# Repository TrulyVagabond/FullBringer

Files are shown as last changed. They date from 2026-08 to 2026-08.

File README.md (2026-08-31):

[][contributors-url]
[][forks-url]
[][stars-url]
[][issues-url]
[][license-url]

<br />
<div align="center">
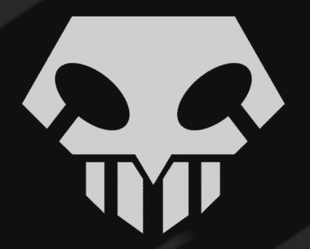
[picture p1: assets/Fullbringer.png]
  
  <h3 align="center">FullBringer</h3>

  <p align="center">
    A Cooler PCB Card
    <br />
    <br />
    <a href="https://github.com/TrulyVagabond/FullBringer/blob/main/JOURNAL.md">Journal</a>
    &middot;
    <a href="https://github.com/TrulyVagabond/FullBringer/issues">Report Bug</a>
    &middot;
    <a href="https://github.com/TrulyVagabond/FullBringer/issues">Request Feature</a>
  </p>
</div>

## What is FullBringer?

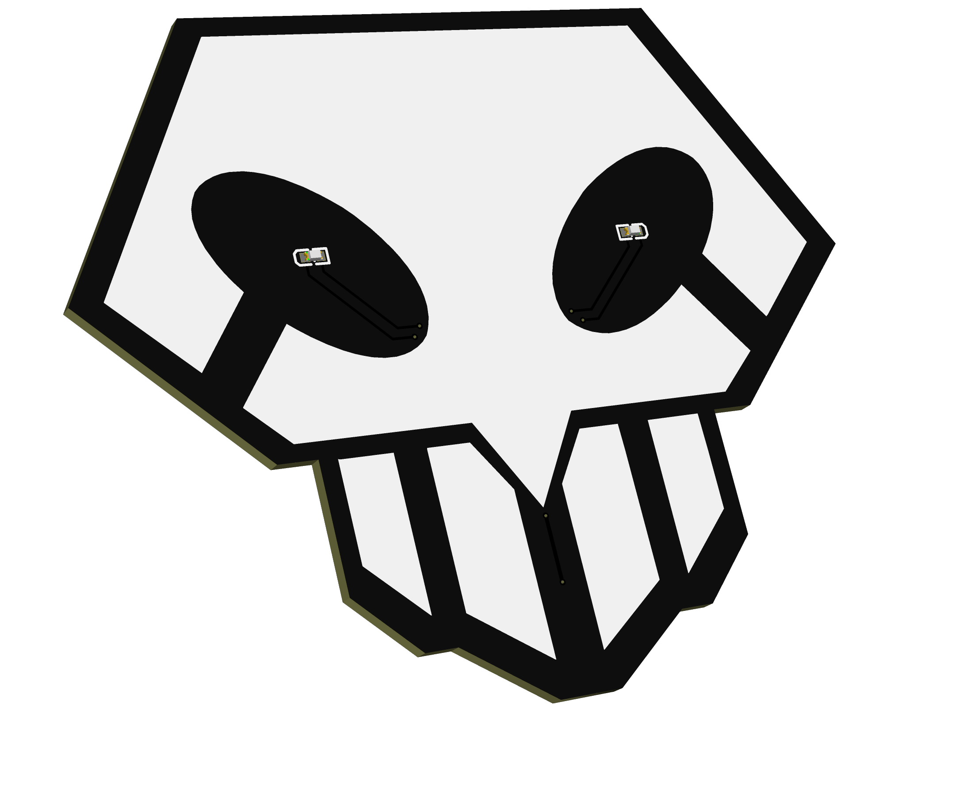
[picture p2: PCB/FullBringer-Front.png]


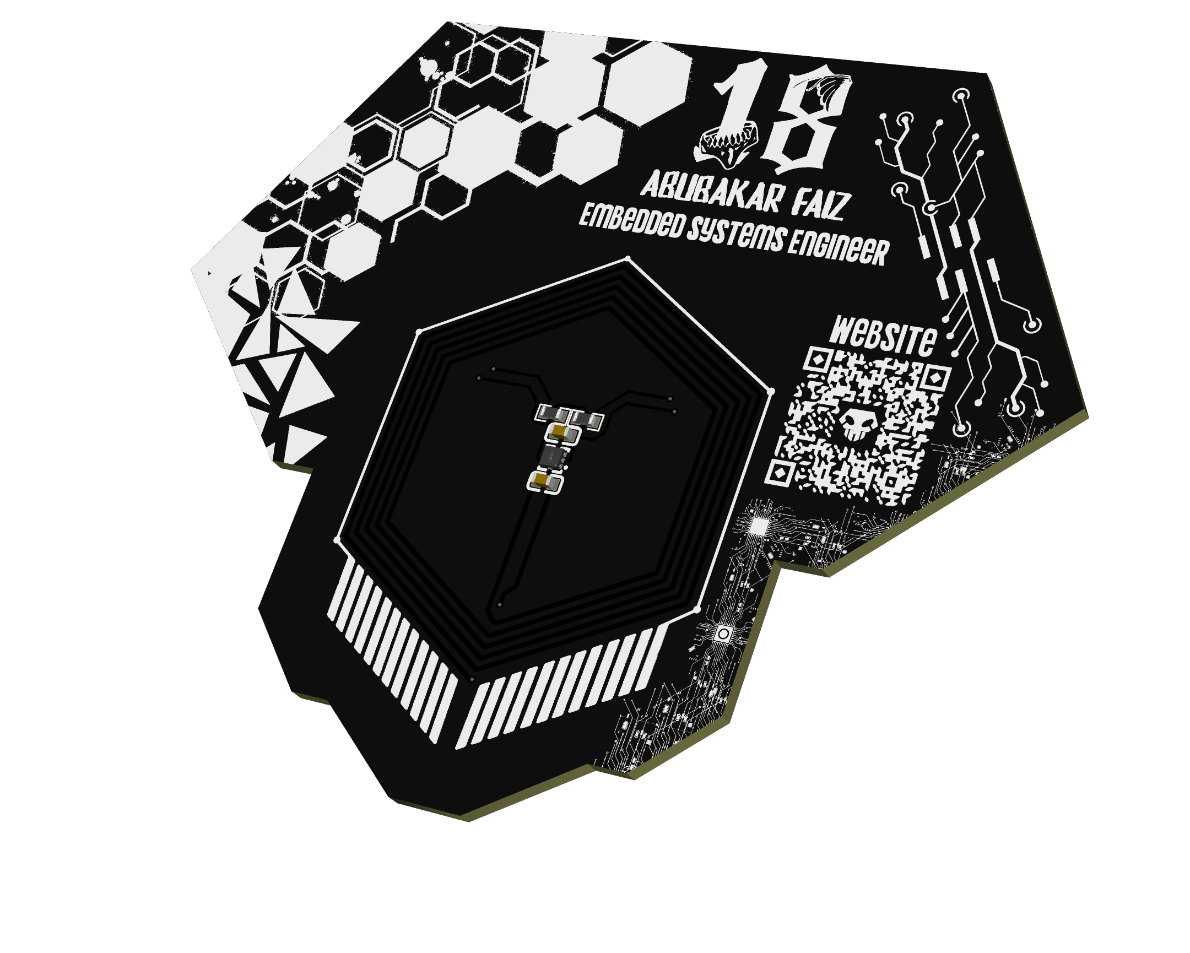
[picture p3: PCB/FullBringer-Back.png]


FullBringer is A PCB Business/Portfolio/ID Card with NFC and Design Inspired by Bleach. There are 2 LED's on the Front and the Entire Circuit on the Bottom Layer. This is Purely Designed to Look Cooler and Impress Recruiters or Friends. The integrated planar antenna harvests power from the phone's magnetic field to illuminate two red LEDs embedded in the skull's eye sockets, while simultaneously broadcasting an NDEF payload (custom URL, or GitHub portfolio) directly to the device.

### Built With

* [][EasyEDA-url]
* [][Inkscape-url]

## Getting Started

To get Your own FullBringer, you need two things.

- PCB
- Money

### Ordering the PCB

1. Navigate to the Gerber Files in the **"Gerber"** Folder. 

2. Download the ".zip" File

3. Upload this '.zip' file to a custom PCB manufacturer (Like PCBWay, OSH Park or JLCPCB)

4. Standard Manufacturing Settings (1.6mm thickness, HASL finish) work Perfectly for this Board.

## Bills Of Materials (BOM)

| Item | Designator | Qty | Value / Param | Package | Description | Manufacturer | MPN | JLCPCB / LCSC Part # |
| :---: | :--- | :---: | :--- | :--- | :--- | :--- | :--- | :---: |
| 1 | **U1** | 1 | 13.56 MHz | XQFN-8 (1.6×1.6mm) | NTAG I²C Plus NFC Transponder IC with Energy Harvesting Rail (`VOUT`) | NXP Semiconductors | `NT3H1101W0FHKH` | [C73156](https://www.lcsc.com/product-detail/C73156.html) |
| 2 | **C1** | 1 | 1 µF, 50V, X5R | 0603 | Energy Harvesting Buffer & Decoupling Capacitor (VOUT to GND) | Samsung Electro-Mechanics | `CL10A105KB8NNNC` | [C15849](https://www.lcsc.com/product-detail/C15849.html) |
| 3 | **C2** | 1 | 33 pF, 50V, C0G/NP0 | 0603 | RF Tank Tuning Capacitor (Parallel across LA/LB terminals) | Samsung Electro-Mechanics | `CL10C330JB8NNNC` | [C1663](https://www.lcsc.com/product-detail/C1663.html) |
| 4 | **R1, R2** | 2 | 470 Ω, 1% | 0603 | Current-Limiting Resistors for Eye LEDs (~1.2 mA per branch) | UNI-ROYAL (厚声) | `0603WAF4700T5E` | [C23179](https://www.lcsc.com/product-detail/C23179.html) |
| 5 | **LED1, LED2** | 2 | 620–625 nm (Red) | 0603 (1608 Metric) | High-Efficiency Red SMD Diffused LEDs (Skull Eye Sockets) | KENTO (广东风华) | `KT-0603R` | [C2286](https://www.lcsc.com/product-detail/C2286.html) |
| 6 | **ANT** | 1 | ~1.65 µH | PCB Trace | 5-Turn Hexagonal Planar Spiral Inductor (0.4 mm width / 0.4 mm spacing) | Custom Embedded | Embedded Copper | *Integrated* | 

### **Total: $6-7** (DON'T SAY IT)

## Using FullBringer

You Just need to Solder the Chip/Capacitors etc (unless you bought from PCBWay). Then Just use the Free NFC tools App for Android/IOS to Setup the NFC. Thats it, your Fullbringer is Ready!

## Special Thanks:

- **EasyEDA** for the Amazing PCB Designing Free Software.

- **Hack Club** for making me Motivated enough to make this.

## License

This Project is Distributed Under MIT License. Check License.txt for More Information.

<!-- MARKDOWN LINKS & IMAGES -->
[contributors-shield]: https://img.shields.io/github/contributors/TrulyVagabond/FullBringer.svg?style=for-the-badge
[contributors-url]: https://github.com/TrulyVagabond/FullBringer/graphs/contributors

[forks-shield]: https://img.shields.io/github/forks/TrulyVagabond/FullBringer.svg?style=for-the-badge
[forks-url]: https://github.com/TrulyVagabond/FullBringer/network/members

[stars-shield]: https://img.shields.io/github/stars/TrulyVagabond/FullBringer.svg?style=for-the-badge
[stars-url]: https://github.com/TrulyVagabond/FullBringer/stargazers

[issues-shield]: https://img.shields.io/github/issues/TrulyVagabond/FullBringer.svg?style=for-the-badge
[issues-url]: https://github.com/TrulyVagabond/FullBringer/issues

[license-shield]: https://img.shields.io/github/license/TrulyVagabond/FullBringer.svg?style=for-the-badge
[license-url]: https://github.com/TrulyVagabond/FullBringer/blob/main/LICENSE

[EasyEDA]: https://img.shields.io/badge/EasyEDA-0177D7?style=for-the-badge
[EasyEDA-url]: https://easyeda.com/

[FreeCAD]: https://img.shields.io/badge/FreeCAD-2D9CDB?style=for-the-badge&logo=freecad&logoColor=white
[FreeCAD-url]: https://www.freecad.org/

[Inkscape]: https://img.shields.io/badge/Inkscape-000000?style=for-the-badge&logo=inkscape&logoColor=white
[Inkscape-url]: https://inkscape.org/

<br>

###### Note: A.I was only used for Research Purposes.

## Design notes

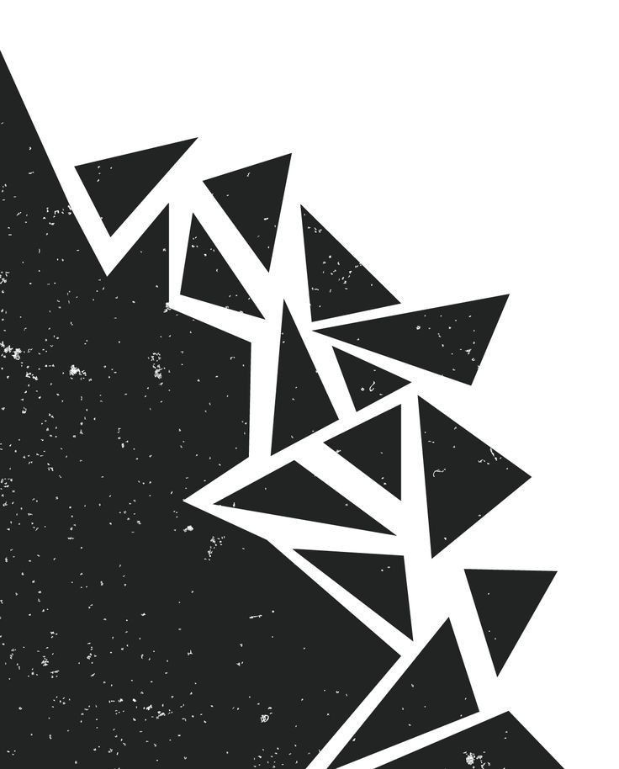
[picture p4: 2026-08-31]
assets/art3.jpg

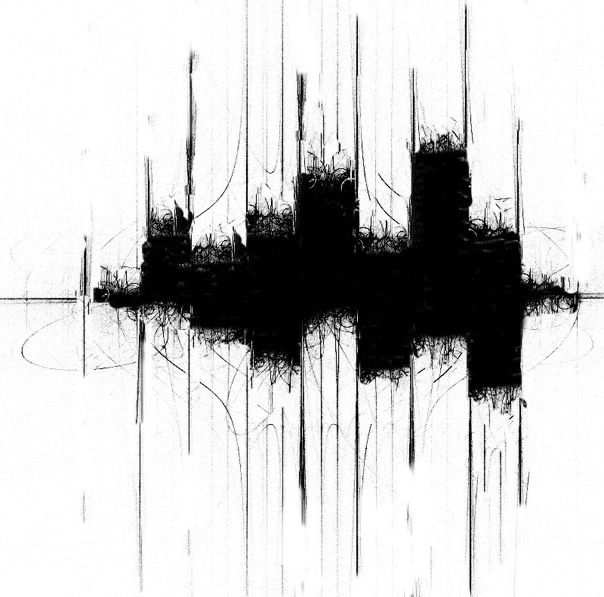
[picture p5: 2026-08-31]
assets/art2.jpg

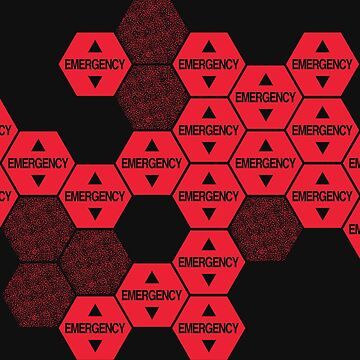
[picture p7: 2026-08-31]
assets/art7.jpg

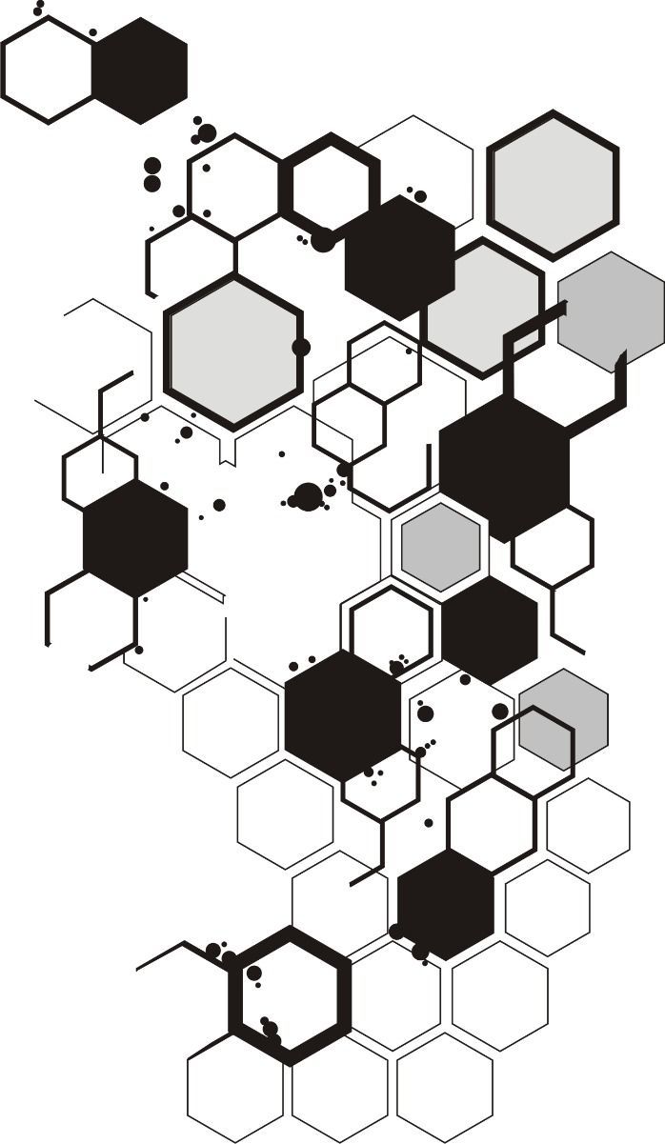
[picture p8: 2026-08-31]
assets/art1.jpg

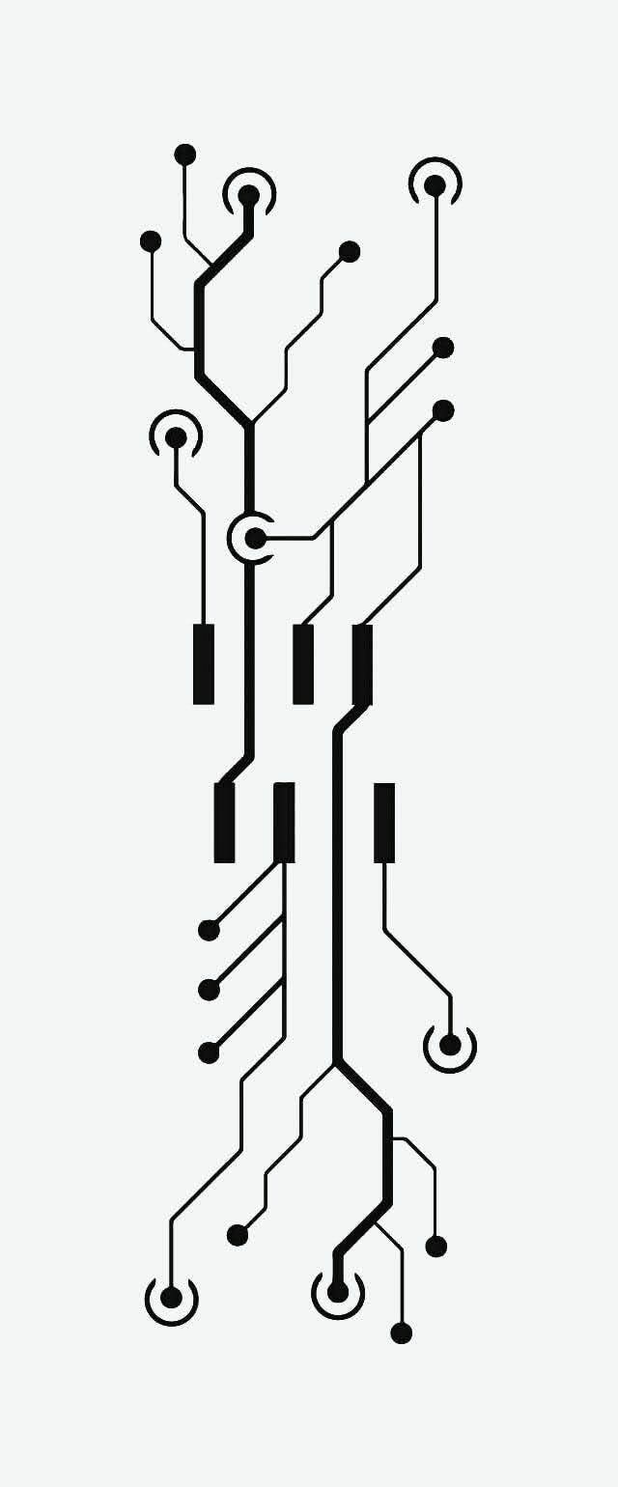
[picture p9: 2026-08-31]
assets/art.jpg

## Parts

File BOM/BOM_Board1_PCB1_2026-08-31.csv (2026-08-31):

No. | Quantity | Comment | Designator | Footprint | Value | Manufacturer Part | Manufacturer | Supplier Part | Supplier | Name | LCSC Stock | LCSC Price
1 | 1 | 1uF | C1 | C0603 | 1uF | CL10A105KB8NNNC | SAMSUNG(三星) | C15849 | LCSC | 1uF
2 | 1 | 33pF | C2 | C0603 | 33pF | CL10B104KA8NNNC | SAMSUNG(三星) |  | LCSC | 33pF
3 | 2 | KT-0603R | LED1,LED2 | LED-SMD_L1.6-W0.8-R-RD |  | KT-0603R | KENTO | C2286 | LCSC | KT-0603R
4 | 2 | 470Ω | R1,R2 | R0603 | 470Ω | 0603WAF4700T5E | UNI-ROYAL(厚声) | C23179 | LCSC | 470Ω
5 | 1 | 13.56MHz | U1 | XQFN-8_L1.6-W1.6-P0.50-BR | 13.56MHz | NT3H1101W0FHKH | NXP(恩智浦) | C73156 | LCSC | 13.56MHz

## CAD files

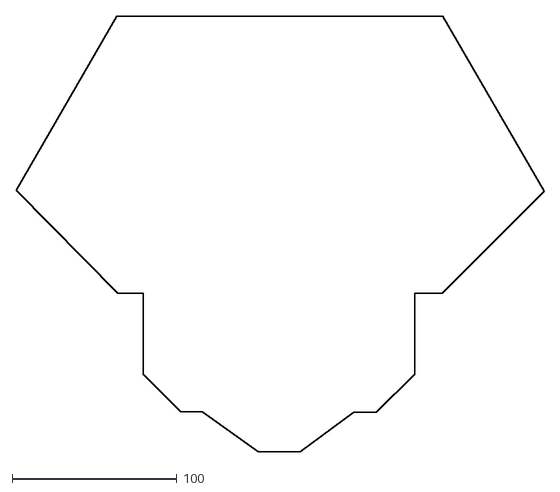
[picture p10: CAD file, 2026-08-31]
assets/Fullllbringer.dxf
320.6 x 264.6

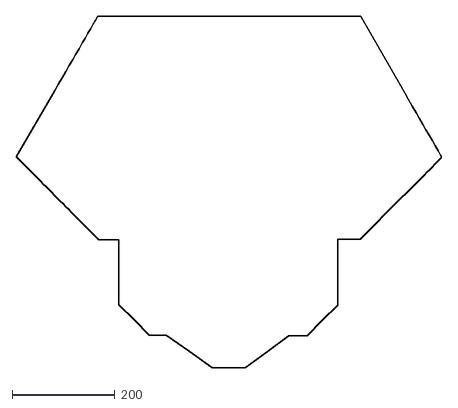
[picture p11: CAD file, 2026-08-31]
assets/Fullbringer.dxf
825.5 x 682.0

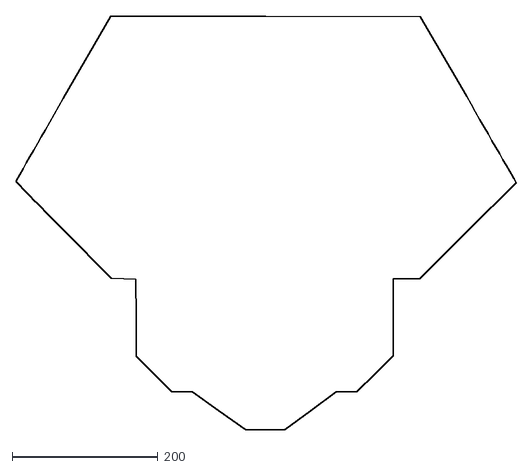
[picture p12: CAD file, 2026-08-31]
assets/Fulllbringer.dxf
685.4 x 567.0

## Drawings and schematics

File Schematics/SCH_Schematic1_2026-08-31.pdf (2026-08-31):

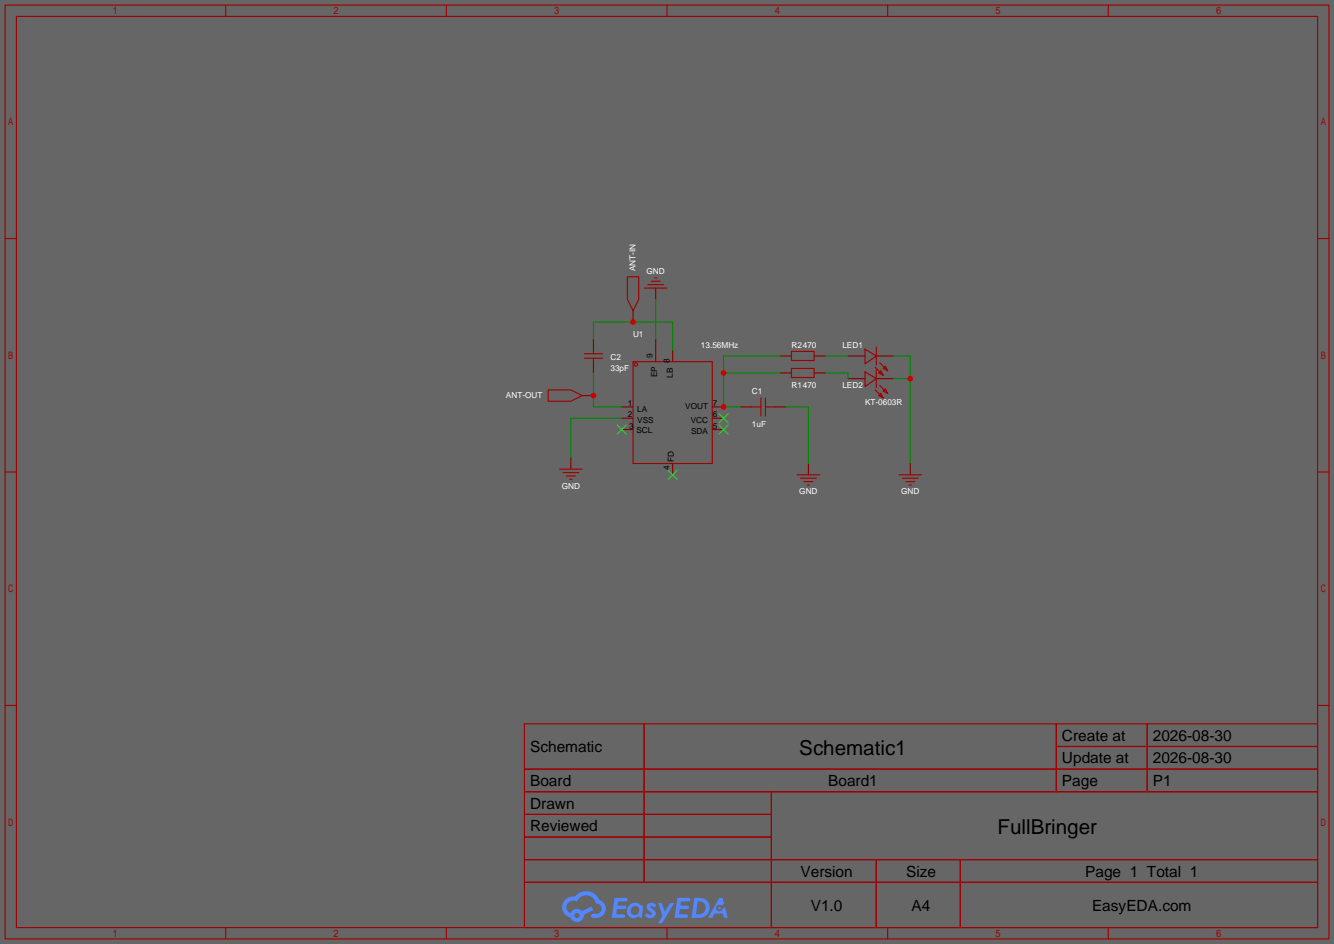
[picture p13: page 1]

Schematic | Schematic1 | Create at | 2026-08-30

Update at | 2026-08-30

Board | Board1 | Page | P1
Drawn | | FullBringer
Reviewed

Version | Size | Page 1 Total 1
V1.0 | A4 | EasyEDA.com

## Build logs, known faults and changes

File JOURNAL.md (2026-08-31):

# FullBringer: A PCB Business/Portfolio/ID Card with NFC and Design Inspired by Bleach

## 29-08-2026

### FullBringer: Born

I wanted to make a cool looking PCB Card which has NFC, this way i would be able to work with NFC and learn how it works, and the theme for the pcb would be Bleach's Fullbring, Its a Card type item Ichigo Uses to transform and gain powers of Fullbringers. So this was the Perfect project to get Hours and still being fun and Practical instead of A.i Slop. Since I needed the Best NFC Chip, I chose to go with **NT3H1101W0FHKH**, because it has the capability of transmitting somewhat larger data (~1000 bytes), so I could use it for anything basically, like showing a link when Scanned, or sending a message with my number saved, this would be really helpfull for:

- Networking
- Looking Cool
- Impressing Recruiters

Hence with all these benefits, i had to build this thing. I First Started with getting the Board Outline right, and I did that by importing the Fullbring picture into Inkscape (you can also use any vector based software), then i used the pen tool to outline the shape, After that I exported only the vector shape into .dxf format. and then I uploaded that into EasyEDA by using the Import option and selecting DXF file. I had some problems like not getting the dimensions correct, like for example, the board outline was like 27inch lol, if i hadn't noticed it would've been a problem, well after fixing that it was pretty easy, i had to work on the Schematic First.

My Plan was to use the NFC Chip to power the LED's inside the Eye Shape, and using a Red LED is the best option because it requires the lease amount to current to lit up (1.8V-2V), which the NFC chip can provide just from the Phones RF signals. I also needed to add resistors and capacitors to everything. The Most Important being the Antenna.

The Antenna is the Main thing of an NFC Device, the bigger it is the better the scannability, so I had to make it bigger and Hexagonal Shape.

We have to Calculate the Frequency and Use the Most compatible Tuning Capacitor in order to get 13.56MHz, and thats a bit of math, you have to use a website and add the details of your Exact Shape like how many turns the coil have and inner/outter diameter. Well After Calculating that, the entire circuit is pretty easy. and after wiring everything this is how it looks:

Schematics:

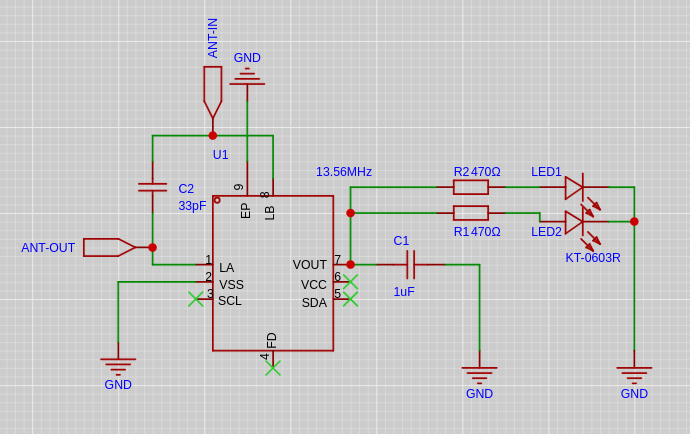
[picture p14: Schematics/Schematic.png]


PCB:

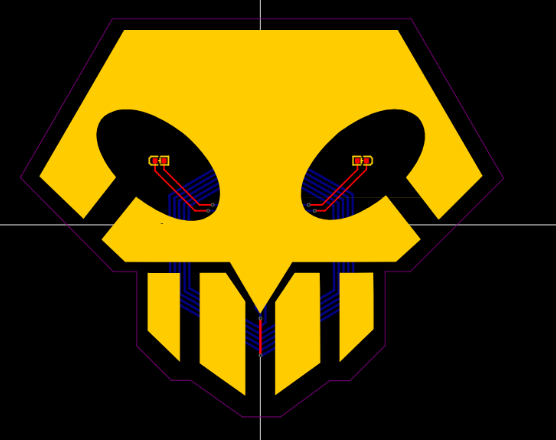
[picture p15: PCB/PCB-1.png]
PCB-1

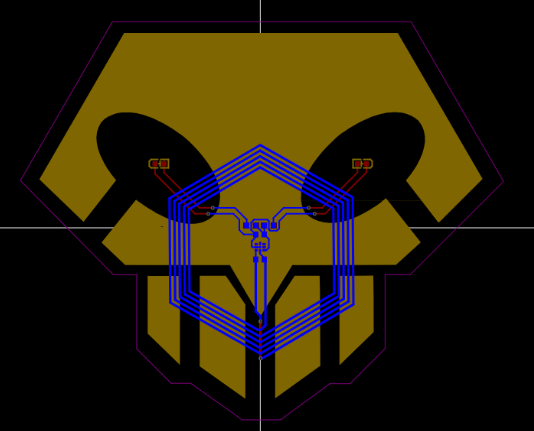
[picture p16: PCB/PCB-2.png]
PCB-2


The wiring turned out so Peak. 

[Lapse-Recording](https://lapse.hackclub.com/timelapse/x4mbCJO4-PNi)

## 30-08-2026 to 31-08-2026

### Finishing the Design:

These days I worked on the Design of the Card. I was going for the Cyberpunk/Bleach Aesthetic, so I looked up stuff on pinterest etc and imported stuff I liked. Art is a Part of Me, I can't just let it be Bland. Its Hard to Explain the Design aspect so let me just show you how it looks:

PCB-Front
PCB-Back

I'm Very Proud of the Design, This was a pretty Easy and Fun Project, maybe I'll make something like this again but with a different Design. That's it for this Project.

[Lapse-Recording](https://lapse.hackclub.com/timelapse/lwEcdGAcOBfR)
[Lapse-Recording](https://lapse.hackclub.com/timelapse/QgyZu3c77ZgE)

//***See you Space Cowboy***
